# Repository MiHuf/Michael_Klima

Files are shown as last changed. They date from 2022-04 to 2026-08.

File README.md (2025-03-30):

[Zu bearbeiten mit keenwrite.bin oder retext,  File README.md, Version 2025-03-30]: #
# Michael_Klima

Michaels Raumklima-Monitor. Inspiriert durch den Artikel
"IKEA Vindiktning hacken", siehe Make 5/2021, Seite 14 ff und hier: <https://techtest.org/anleitung-wlan-feinstaub-und-temperatur-sensor-ikea-vindriktning-hack/>

Der Code ist vorbereitet für den Anschluß weiterer Sensoren.
Im Original: VINDRIKTNING Ikea Luftgüte Sensor -> AdafruitIO

Mai 2022: Absolute (aber ungenaue) Helligkeitsmessung mit einem LDR Photowiderstand. Parameter müssen in der jeweiligen Zugangsdaten-Datei xxx.h angepasst werden. Siehe LDR-Photometer.pdf.

Sept. 2023: Luftdruck-Sensor BME280 eingebaut, CO2-Sensor SCD-30 vorbereitet.

Okt. 2024: Doku ergänzt.

Nov. 2024: MQTT funktioniert, Doku aktualisiert

Dez. 2024: MQTT jetzt sowohl mit Port 1883 als auch mit Port 8883 (TLS)

Mrz. 2025: Erweitert auf beliebig viele (zur Zeit 10) DS18x20 Sensoren

## Konfiguration und Installation

  1. Den Projekt-Ordner "Michael_Klima" von github.com/MiHuf/ klonen.

  2. Der Mircocontroller "Wemos D1 Mini ESP8266" wird programmiert mit der Arduino IDE <https://www.heise.de/ct/artikel/Arduino-IDE-installieren-und-fit-machen-fuer-ESP8266-und-ESP32-4130814.html>. Die Sprache ist im Wesentlichen C++.  
Vorher müssen noch einige Dateien angepasst werden:

  3. ***Datei "Michael_Klima.h", Zeile 51:***

      #include "privat.h"   
Die Datei "privat.h" enthält persönliche Zugangsdaten. Am besten nimmt man die als Gerüst und kopiert sie in eine neue Datei, z.B. "_mein_privat.h". Alle Dateien mit einem Unterstrich am Anfang des Namens werden von git nicht im öffentlichen Repository gespeichert.  
Anschließend muss die Zeile 56 entsprechend angepasst werden:  
  #include "_mein_privat.h"  

  4. ***Datei "_mein_privat.h":*** 
  
      4.1. In den Zeilen 23 bis 52 sind die aktuell vorhandenden Sensoren definiert, die Zeilen können gelöscht oder umgeordnet werden. 
 
      4.2. In die Sektion "\***** My Settings" kommen dann die privaten Zugangsdaten:  
   #define WIFI_SSID "xxx"  
   #define WIFI_PASS "yyy"  
Das sind die Zugangsdaten zum lokalen WLAN des Routers und ggf. zum Internet.

     4.3. Falls erforderlich, Daten für den MQTT Broker konfigurieren: TOPIC, MQTT_BROKER, MQTT_PORT,  MQTT_USER, MQTT_PASS, ...  
     Achtung: Falls "MQTT_PORT 8883" für TLS gesetzt wird, muss zusätzlich eine Zeile  
   #define MQTT_TLS  
eingefügt werden. Für "MQTT_PORT 1883" muss diese Zeile auskommentert werden.  

      4.4 Der Wemos D1 Mini ESP8266 in dem Modul spannt eigenes WLAN auf, das wird konfiguriert in den Zeilen  
   #define APSSID "zzz"  
   #define OPEN_WIFI  
Das sind die Zugangsdaten zum internen WLAN des ESP8266 (ohne Passwort).

5. ***Anschließend mit der Arduino IDE kompiliern,*** das Modul mit einem Mirco-USB Kabel an den PC anschließen und den Binär-Code auf den D1 Mini hochladen.

    Der ESP8266 konfiguriert sich dann und startet das Programm. Das kann bis zu 2 Minuten dauern, am Ende wird die eingebaute LED fünf mal blinken.

6. ***Für den nächsten Schritt gibt es 2 Möglichkeiten:***

    6.1 Mit einem anderen PC / Touchpad / Handy das WLAN Netzwerk scannen und mit der in Abschnitt 4.2 definierten APSSID (z.B. "zzz") verbinden.

      Dann mit einem Browser (Firefox, Chrome) die Seite `http://192.168.4.1` öffnen. Dann sollte sich eine Seite mit wichtigen Informationen über das Netzwerk öffnen. Merke dir aus der Zeile "External WLAN SSID" den Wert von "IP address" und aus der folgenden Zeile den Wert von "Hostname on Router".

      Falls in der Zeile "External WLAN SSID" keine IP-Adresse angezeigt wird, hat die Verbindung zum WLAN des Routers nicht geklappt. Überprüfe die Zugangsdaten und wiederhole ab Abschnitt 4.2.

    6.2 Gehe auf die Administrations-Seite des Routers, lass dir im Abschnitt "WLAN > Funknetz" die verbundenen Geräte anzeigen. Der ESP8266 sollte unter dem Namen Raumklima-XXX sichtbar sein, wobei XXX die letzten 6 Hex-Ziffern der MAC Addresse ist. Merke dir die zughörige IP-Adresse.

7. ***Geschafft!***
  Ab jetzt sollte der Raumklima Monitor von überall im LAN mit einem Browser sichtbar sein, entweder über die obige IP-Adresse oder über die URL `"http://raumklima-xxx"`.

8. ***Optional:***
  Um einen Zugriff von außen übers Internet einzurichten, muss man im Router einen DDNS-Client installieren und konfigurieren und ferner für raumklima-xxx eine Port-Weiterleitung zur <IP-Adresse des Moduls>:80 erstellen.

## Life Demo

Klicke hier: <http://hufschmidt.ddns.krude.de:8086/> oder <http://hufschmidt.ddns.krude.de:8087/>

## Setup März 2022:

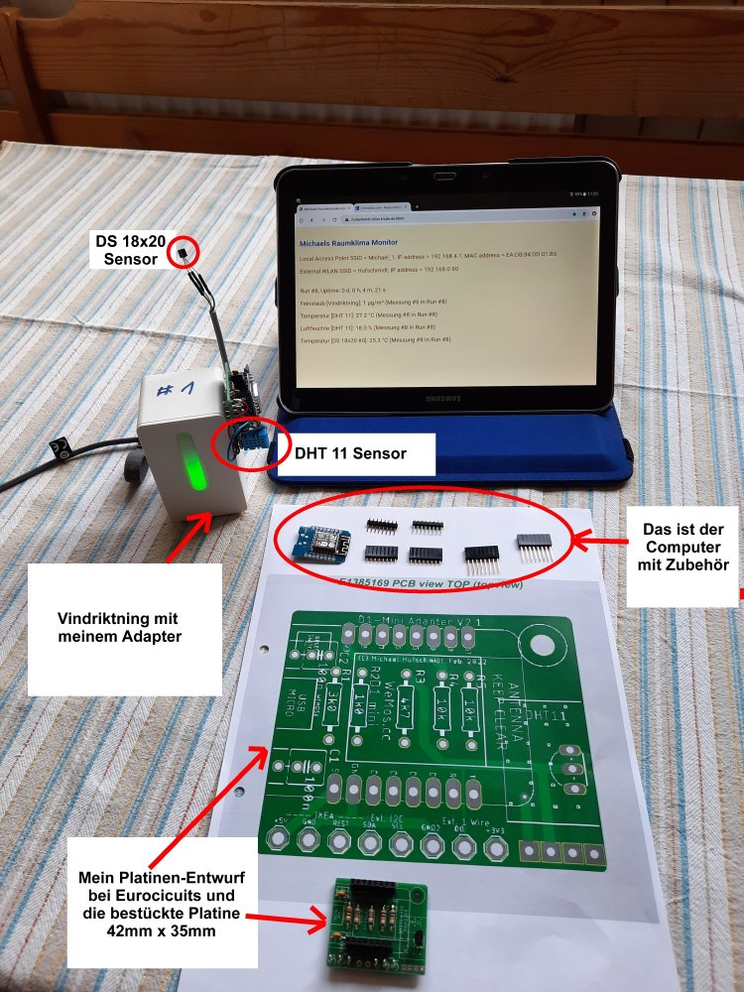
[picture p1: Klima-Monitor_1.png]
Foto Setup


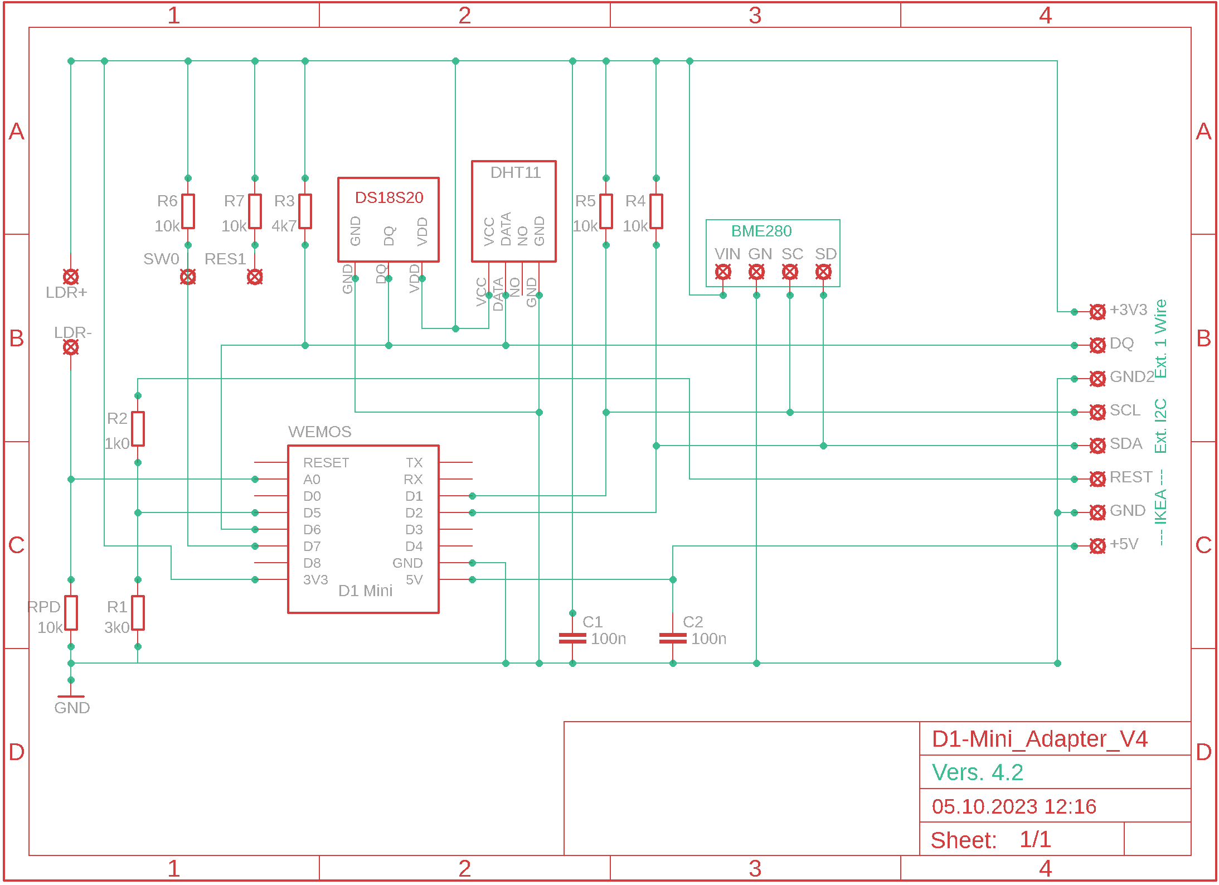
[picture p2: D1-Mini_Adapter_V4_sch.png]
pdf Adapter Schematic Schaltplan


Und hier die Adapter-Platine (35mm x 42mm):

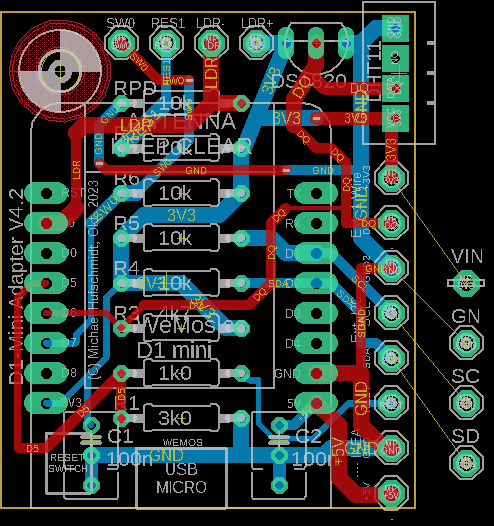
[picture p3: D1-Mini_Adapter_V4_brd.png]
pdf Adapter PCB Platine


## Quellen für den Arduino Code und für MQTT  Broker
|Was |URL|
|---|---|
|ESP8266:|<https://github.com/esp8266/Arduino/tree/master/libraries/ESP8266WiFi/>|
|Time-Server:|<https://werner.rothschopf.net/201802_arduino_esp8266_ntp.htm>|
|OneWire:|<https://github.com/PaulStoffregen/OneWire/blob/master/OneWire.h>|
| |<https://www.arduino.cc/reference/en/libraries/onewire/>|
|DS18B20:|<https://github.com/milesburton/Arduino-Temperature-Control-Library/blob/master/DallasTemperature.h>|
|DHT11:  |<https://cdn-learn.adafruit.com/downloads/pdf/dht.pdf>|
| |<https://github.com/adafruit/DHT-sensor-library>|
|BME280: |<https://www.az-delivery.de/products/gy-bme280>|
|SCD-30: |<https://www.adafruit.com/product/4867>|
| |<https://learn.adafruit.com/adafruit-scd30/arduino>|
|MQTT Client Lib|<https://github.com/knolleary/pubsubclient>|
|MQTT Broker Mosquitto:|<http://www.steves-internet-guide.com/install-mosquitto-linux/>|
|InfluxDB:|<https://www.ionos.de/digitalguide/hosting/hosting-technik/was-ist-influxdb/>|
|Grafana: |<https://grafana.com/>|
|MQTT Client Software zum Testen|<http://mqtt-explorer.com/>|
|MQTT Broker, Übersicht|<https://mntolia.com/10-free-public-private-mqtt-brokers-for-testing-prototyping/>|
|MQTT Broker HiveMQ:| <https://www.hivemq.com/>|
|MQTT Broker Cedalo / Pro Mosquitto| <https://test.mosquitto.org/>|
|MQTT Broker flespi|<https://flespi.com/>|
|MQTT Broker sensatio:|<https://www.sensatio.io/>|

---

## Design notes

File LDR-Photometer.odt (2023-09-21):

LDR-Photometer

Dies ist der Versuch, eine quantitative Helligkeitsanzeige mit einem LDR Photowiderstand zu realisieren. Hardware ist ein ESP8255 (https://www.wemos.cc/en/latest/d1/d1_mini.html) Microcontroller an dessen Analog-Eingang A0 neben einem Pull-Down Widerstand Rpd ein LDR vom Typ GL 55xx angeschlossen ist (Preis für 30 Stück: 1,89 € bei Eckstein (https://eckstein-shop.de/30pcs6ValuesLichtempfindlicheWiederstC3A4ndePhotoresistor550655165528553755395549)).

Hier das Datenblatt (https://www.kth.se/social/files/54ef17dbf27654753f437c56/GL5537.pdf); die wichtigsten Daten für die Typen:

Typ | Light Resistance R10 / kΩ | Dark Resistance R0 / MΩ
GL 5516 | 5 – 10 | 0.5 | 0.5
GL 5528 | 10 – 20 | 1 | 0.6
GL 5537-1 | 20 – 30 | 2 | 0.6
GL 5537-2 | 30 – 50 | 3 | 0.7
GL 5539 | 50 – 100 | 5 | 0.8
GL 5549 | 100 – 200 | 10 | 0.9

Die Sensitivität γ ist im Datenblatt definiert durch die Gleichung wobei R10 bzw. R100 die Widerstandswerte bei einer Beleuchtungsstärke von B = 10 lx bzw. 100 lx sind. Die Einheit der Beleuchtungsstärke ist das Lux (https://de.wikipedia.org/wiki/Beleuchtungsstärke), abgekürzt lx.

Für eine beliebige Beleuchtungsstärke B definiere ich nun RB als den Widerstandswert des mit der Beleuchtungsstärke B bestrahlten LDRs sowie . Für das interessierende Intervall von B = 1 lx (Kerze in 1 m Abstand) bis 10.000 lx (im Sommer im Schatten) werden nun folgenden Annahmen gemacht:

- Es gilt , d.h. es zeigt sich in der doppelt logarithmischen Darstellung ein über mehrere Dekaden linearer Verlauf zwischen Widerstandswert und Beleuchtungsstärke. Das wird nahegelegt durch die Graphen im Datenblatt.
- Die Temperaturabhängigkeit kann vernachlässigt werden.

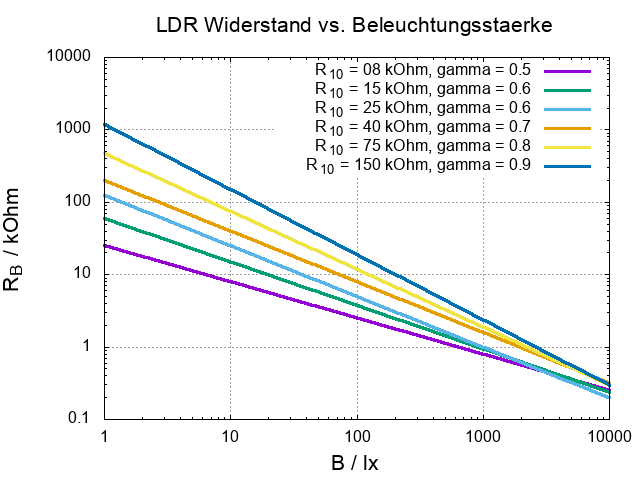
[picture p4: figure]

Damit kann nun RB aus R10 und γ wie folgt berechnet werden:

(1)

und umgekehrt:

(2) .

Der 10-Bit A/D Wandler im ESP8255 hat einen Eingangsspannungs-Bereich zwischen 0 V und 3,3 V. (Achtung! Das gilt nur für die Development Boards wie ESP8266 12-E NodeMCU Kit, WeMos D1 Mini, … Der nackte ESP8255 Chip hat einen Eingangsspannungs-Bereich von 0 V bis 1 V.) Der Eingang wird in der Arduino IDE angesprochen mit der Funktion ADC = analogRead(A0), die eine Integer Zahl zwischen 0 und 1024 zurückgibt.

Mit einem Spannungsteiler bestehend aus einem Pull-Down Widerstand Rpd zwischen A0 und GND und dem LDR zwischen A0 und +3,3 V (mit dieser Polung ergibt sich ein monoton wachsender Zusammenhang zwischen ADC-Wert und Beleuchtungsstärke B) ergibt sich dann:

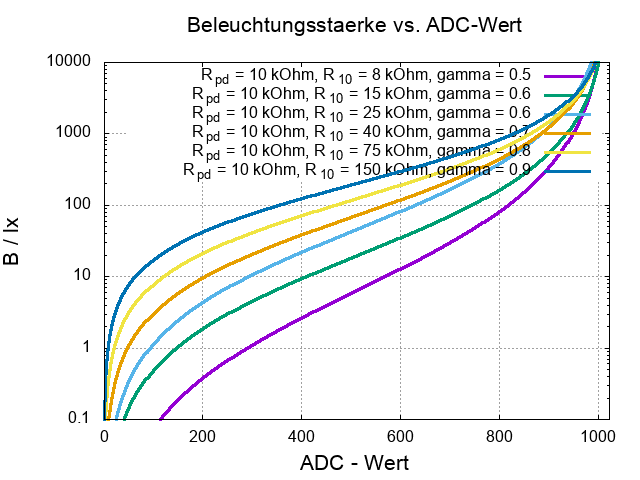
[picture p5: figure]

(3) .

Gleichung (3) eingesetzt in (2) liefert schließlich den mathematischen Zusammenhang zwischen ADC-Wert und Beleuchtungsstärke B:

(4) .

Wertetabelle

Angenommene Parameter für Typ GL 5539:

Rpd = | 10.000 | Ω
R10 = | 75.000 | Ω
gamma = | 0,8
ADC-Wert | RB / Ω | B / lx
2 | 5.110.000 | 0,05
5 | 2.038.000 | 0,16
10 | 1.014.000 | 0,39
20 | 502.000 | 0,93
50 | 194.800 | 3,03
100 | 92.400 | 7,70
200 | 41.200 | 21,14
500 | 10.480 | 117,05
800 | 2.800 | 609,37
1000 | 240 | 13.139,01

Michael Hufschmidt

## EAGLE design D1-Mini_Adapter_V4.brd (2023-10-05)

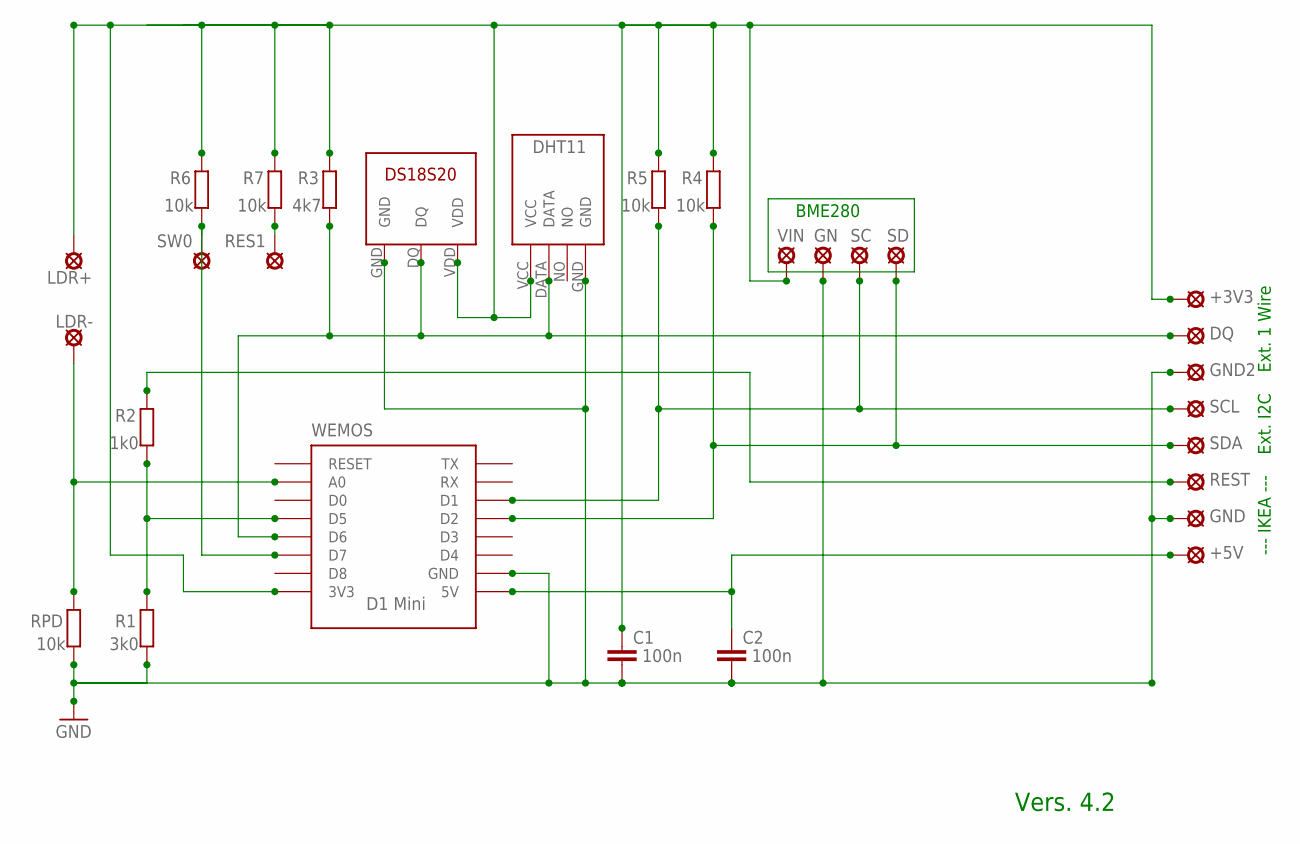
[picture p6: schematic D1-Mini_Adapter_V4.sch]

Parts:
+3V3, +5V: SE13
C1, C2: 100n; C025_050-045X075
DQ: SE13
DS1820: DS18S20; DS18S20-PACKAGE
GN: SE13
GND, GND2: SE13
LDR+: SE13
LDR-: SE13
R1: 3k0; 0207/10
R2: 1k0; 0207/10
R3: 4k7; 0207/10
R4, R5, R6, R7: 10k; 0207/10
RES1: SE13
REST: SE13
RPD: 10k; 0207/10
SC: SE13
SCL: SE13
SD: SE13
SDA: SE13
SW0: SE13
U$1: DHT11-PION.
VIN: LSP13
WEMOS: D1 Mini; WEMOS-D1-MINI

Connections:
3V3: +3V3.MP, C1.1, DS1820.VDD, LDR+.MP, R3.2, R4.2, R5.2, R6.2, R7.2, U$1.VCC, VIN.MP, WEMOS.3V3
+5V: +5V.MP, C2.1, WEMOS.5V
D5: R1.2, R2.1, WEMOS.D5
DQ: DQ.MP, DS1820.DQ, R3.1, U$1.DATA, WEMOS.D6
GND: C1.2, C2.2, DS1820.GND, GN.MP, GND.MP, GND2.MP, R1.1, RPD.1, U$1.GND, WEMOS.GND
LDR: LDR-.MP, RPD.2, WEMOS.A0
RES1: R7.1, RES1.MP
REST: R2.2, REST.MP
SCL: R5.1, SC.MP, SCL.MP, WEMOS.D1
SDA: R4.1, SD.MP, SDA.MP, WEMOS.D2
SW0: R6.1, SW0.MP, WEMOS.D7

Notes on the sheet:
--- IKEA ---
Ext. I2C
Ext. 1 Wire
Vers. 4.2
BME280

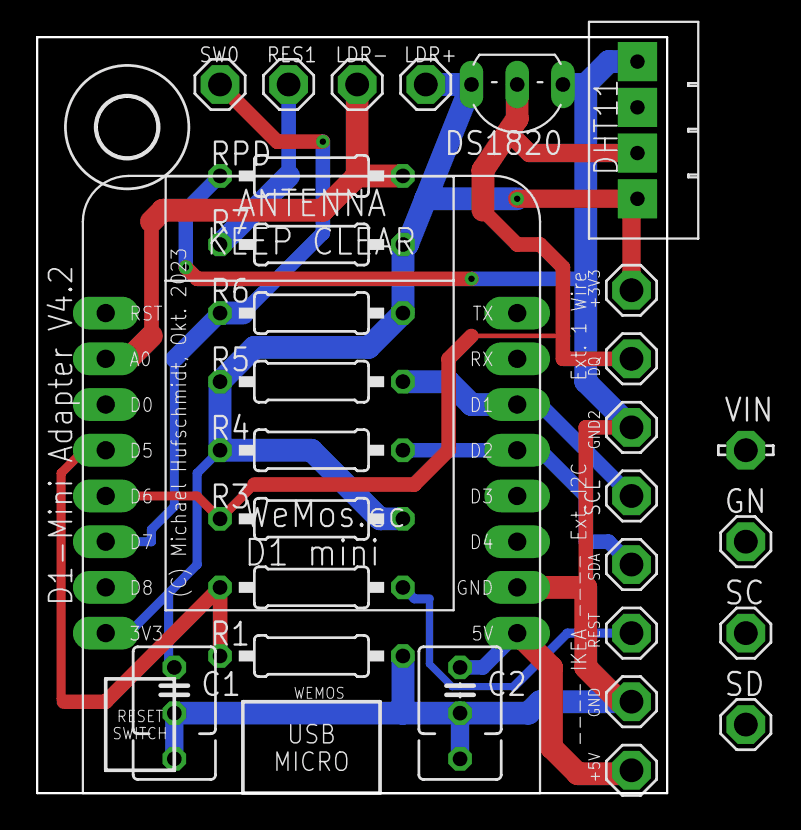
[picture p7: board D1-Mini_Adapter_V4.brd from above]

Board: 2 copper layers, 35.0 x 42.0 mm, 30 parts (0 on the bottom side), 11 nets.

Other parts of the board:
U$2: 3,3

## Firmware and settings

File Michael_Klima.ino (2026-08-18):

/*****************************************************************************
   File:              Michael_Klima.ino, Version 1.0
   Created:           2021-12-17
   Last modification: 2026-08-18
   Program size:      Global Vars: 36604 / 80192 bytes (45%),
    (using privat.h)  Instruction RAM: 63003 / 65536 bytes (96%)
                      Code in Flash: 416232 / 1048576 bytes (39%)
   Author and (C):    Michael Hufschmidt <michael@hufschmidt-web.de>
   Projekt Source:    https://github.com/MiHuf/Michael_Klima
   License:           https://creativecommons.org/licenses/by-nc-sa/3.0/de/
 * ***************************************************************************/
const String version = "2026-08-18";
const String ide = "arduino IDE 2.3.10";
/* Michaels Raumklima-Monitor. Inspiriert durch den Artikel "IKEA Vindiktning
   hacken", siehe Make 5/2021, Seite 14 ff und hier:
   https://techtest.org/anleitung-wlan-feinstaub-und-temperatur-sensor-ikea-vindriktning-hack/
   
   Im Original: VINDRIKTNING Ikea Luftguete Sensor -> AdafruitIO
   Siehe https://github.com/MiHuf/Michael_Klima#readme
   in the IDE: Include board
          https://arduino.esp8266.com/stable/package_esp8266com_index.json

  Additional board manager URLs: https://arduino.esp8266
  Boaard: LOLIN(WEMOS) D1 R2 & mini
 * ***************************************************************************/

// ***** Includes
#include <functional>
#include <ESP8266WiFi.h>
#include <ESP8266WebServer.h>
#include <time.h>
#include <TZ.h>
#include <SoftwareSerial.h>
// https://github.com/knolleary/pubsubclient
#include <PubSubClient.h>
#include <CertStoreBearSSL.h>      // needed for HiveMQ with TLS (Port 8883)
#include <DallasTemperature.h>
// ***** For BME280 and SCD-30
// https://www.az-delivery.de/products/gy-bme280 (BME280)
// #include <OneWire.h>
// #include <Wire.h>
#include <Adafruit_Sensor.h>
// #include <DHT-sensor-library>
#include <DHT.h>
#include <Adafruit_BME280.h>
// https://www.adafruit.com/product/4867  (SCD-30)
// https://learn.adafruit.com/adafruit-scd30/arduino
#include <Adafruit_SCD30.h>
// ***** External definitions, constants and variables
#include "Michael_Klima.h"

// ***** Pin definitions
#define D1_MINI
#ifdef D1_MINI  // true for D1 Mini, =D4
  #define AN LOW
  #define AUS HIGH
#else                    // not a D1 Mini
  #define LED_BUILTIN 1  // LED for Digistump
  #define AN HIGH
  #define AUS LOW
#endif
// Original-Version aus Make 05/21:
// Version fuer mein Adapter-Board:
constexpr static const uint8_t PIN_UART_RX = D5;   // =GPIO14, used by IKEA SoftwareSerial
constexpr static const uint8_t PIN_UART_TX = D7;   // =GPIO13, used by IKEA SoftwareSerial
constexpr static const uint8_t SW0 = D7;           // =GPIO13
constexpr static const uint8_t SW1 = D5;           // =GPIO14
// ***** Warning! Boot fails if D3 or D4 are pulled LOW !!!
constexpr static const uint8_t SW2 = D3;           // =GPIO0, *** Warning ***
constexpr static const uint8_t SW3 = D4;           // =GPIO2  *** Warning, LED_BUILTIN ***
constexpr static const uint8_t ONE_WIRE_BUS = D6;  // =GPIO12 am Wemos D1 Mini
// default I2C Pins already defined in Aruino.h:
// constexpr static const uint8_t SCL = D1;        // =GPIO5, default I2C Pins
// constexpr static const uint8_t SDA = D2;        // =GPIO4, default I2C Pins
constexpr static const uint8_t ADC0 = A0;          // = Analog input, Pin 17

// ***** Global Settings
#define MY_TZ "CET-1CEST,M3.5.0/02,M10.5.0/03"
const String wotag[] = { "So", "Mo", "Di", "Mi", "Do", "Fr", "Sa" };
const uint8_t BLINK_COUNT = 5;  // Default Anzahl Lichtblitze
const uint16_t PUNKT = 200;     // Punktlaenge (Norm = 100 ms bei 60 BpM)
const uint16_t ABSTAND = 500;   // Punkt-Strich Abstand (Norm = 100 ms)
const uint16_t ZEICHEN = 1500;  // Buchstaben-Abstand im Wort (Norm = 3x Punkt)
//* Set these to your desired credentials. */
const char* extSsid = WIFI_SSID;
const char* extPassword = WIFI_PASS;
const char* mySsid = APSSID;
const char* myPassword = APPSK;
const char* mqtt_broker = MQTT_BROKER;
#ifdef MQTT_USER
  const char* mqtt_user = MQTT_USER;
  const char* mqtt_password = MQTT_PASS;
#else
  const char* mqtt_user = "";
  const char* mqtt_password = "";
#endif
#ifndef MQTT_CLIENT
  // Create a random client ID
  String mqtt_client_id_s = "ESP8266Client-" + String(random(0xffff), HEX);
#else 
  String mqtt_client_id_s = MQTT_CLIENT;
#endif
const char* mqtt_client_id = mqtt_client_id_s.c_str();
const String topic = TOPIC;
const uint8_t msg_buffer_size = MSG_BUFFER_SIZE;


// ***** Global Variables
String localIP_s, macAddress_s, hostname_s, externalIP_s, mqttWeb_s = MQTT_WEB;
bool wlanOK = false;
bool mqttConnectOK = false;
String mqtt_broker_s = String(MQTT_BROKER) + ":" + String(MQTT_PORT);
int mqttState = -1;
bool timeOK = false;
bool mySCD_global = false;
uint8_t connect_tries = 0;
time_t now;  // this is the epoch
tm tm;       // time information in a structure
#ifdef MY_TITLE
  String title = MY_TITLE;
#else
  String title = "Michaels Raumklima Monitor";
#endif
int sensorCount = sizeof(sensor) / sizeof(sensor_type);
uint8_t deviceCount = 0;             // Anzahl der OneWire - Clients
uint8_t dallasCount = 0;             // Anzahl der DS18x10 - Sensoren
// DallasTemperature.h, line 63: typedef uint8_t DeviceAddress[8];
DeviceAddress ds_Addr[MAX_DS_COUNT]; // alle  DS 18x20 Sensoren
uint8_t global_n = 0;
uint8_t serialRxBuf[80];
uint8_t rxBufIdx = 0;
unsigned long runID = 0;
unsigned long previousMillis = 0;
char msg[msg_buffer_size];
String startTime = "";
double rpd = RPD;     // LDR Pull-Down Resistor
double r10 = R10;     // LDR R(10 Lux)
double sens = GAMMA;  // LDR Gamma-Value / Sensitivity
uint8_t switches[] = {SW0, SW1, SW2, SW3};

// ***** Objects
SoftwareSerial sensorSerial(PIN_UART_RX, PIN_UART_TX);
ESP8266WebServer webServer(80);
#ifdef MQTT_TLS
  BearSSL::WiFiClientSecure espClient;
// BearSSL::CertStore certStore;
#else
  WiFiClient espClient;
#endif
PubSubClient client(espClient);
OneWire oneWire(ONE_WIRE_BUS);
DHT dht(ONE_WIRE_BUS, DHTTYPE, 6);
DallasTemperature ds(&oneWire);
Adafruit_BME280 bme;   // I2C Communication
Adafruit_SCD30 scd30;  // I2C Communication


// ***** General Functions
void blink(const uint8_t count = BLINK_COUNT) {
  pinMode(LED_BUILTIN, OUTPUT);
  digitalWrite(LED_BUILTIN, AUS);
  delay(ZEICHEN);
  for (uint8_t i = 0; i < count; i++) {
    //    Serial.printf("\nBlink #%d", i);
    digitalWrite(LED_BUILTIN, AN);
    delay(ABSTAND);
    digitalWrite(LED_BUILTIN, AUS);
    delay(ABSTAND);
  }
  delay(ZEICHEN);
  pinMode(LED_BUILTIN, INPUT_PULLUP);
}  // blink()

String deviceAddressToString(DeviceAddress a) {
  char buffer[32];
  snprintf(buffer, 30, "%0x %0x %0x %0x  %0x %0x %0x %0x",
           a[7], a[6], a[5], a[4], a[3], a[2], a[1], a[0]);
  return String(buffer);
}  // deviceAddressToString(...)


String lz(int num) {
  // add leading zero
  if (num >= 10) {
    return String(num);
  } else {
    return "0" + String(num);
  }
}  // lz()

String getTime() {
  String out = "";
  if (timeOK) {
    time(&now);              // read the current time
    localtime_r(&now, &tm);  // update the structure tm with the current time
    out += wotag[tm.tm_wday] + ", den ";
    out += lz(tm.tm_mday) + "."
           + lz((tm.tm_mon + 1)) + "."
           + String((tm.tm_year + 1900));
    out += " ";
    out += lz(tm.tm_hour) + ":"
           + lz(tm.tm_min) + ":"
           + lz(tm.tm_sec);
  }  // if
  return out;
}  // getTime()

String runInfo() {
  unsigned long currentMillis, d, h, m, s;
  currentMillis = millis();
  String info = "";
  s = currentMillis / 1000;
  m = s / 60;
  h = m / 60;
  d = h / 24;
  info += "\nRun #";
  info += String(runID);
  if (timeOK) {
    info += " vom " + getTime();
  }
  info += ", Uptime: " + String(d) + " d, ";
  info += String(h % 24) + " h, ";
  info += String(m % 60) + " m, ";
  info += String(s % 60) + " s ";
  return info;
}  // runInfo()


// ***** Setup Sensors

void Setup_Ikea (){
  // Software Serial für IKEA Sensor
  Serial.printf("Software UART (Ikea) on Pin %d\n", PIN_UART_RX);
  sensorSerial.begin(9600);
} // end Setup_Ikea

void Setup_oneWire() {
  pinMode(ONE_WIRE_BUS, INPUT);
  oneWire.begin(ONE_WIRE_BUS);
  if (oneWire.reset()) {
    Serial.printf("oneWire Bus on Pin %d\n", ONE_WIRE_BUS);
  } else {
    Serial.printf("No devices found on Pin %d\n", ONE_WIRE_BUS);
  }
  oneWire.begin(ONE_WIRE_BUS);
} // end Setup_oneWire()

void Setup_ds() {
  bool retry = true;
  String type;
  dht.begin();
  ds.begin();
  Serial.print("Parasite power is: ");
  if (ds.isParasitePowerMode())
    Serial.println("ON (2 wire)");
  else Serial.println("OFF (3 wire)");
  //  ds.setResolution(9);        // global resulution, default 9 Bit
    for (int i = 0; i < MAX_DS_COUNT; i++) {  // scan DS18x20 sensors
      // delay(1000);
      if (ds.getAddress(ds_Addr[i], i)) {
      type = ds_Addr[i][0] == DS18B20MODEL ? "DS18B20" : "DS18S20 / DS1820";
      Serial.println("Found Device #" + String(i) + " " + type + ", ROM-Address = "
                    + deviceAddressToString(ds_Addr[i]));
      dallasCount += 1;
      // ds.setResolution(ds_Addr[i], 11);     // resolutuion for this sensor
    } // end for - scan DS18x20 sensors
  }  // 
  Serial.printf("Found %d DS18x00 Sensor(s) \n", dallasCount);
} // end Setup_ds();

void Setup_BME280() {
  // Try to initialize Communication to BME280
  bool retry = true;
  uint8_t connect_tries = 0;
  unsigned status;
  delay(200);
  while (retry) {
    connect_tries += 1;
    retry = connect_tries < MAX_TRIES;
    status = bme.begin();
    if (status) {
      retry = false;
      Serial.println("Communication to BME280 established after " + String(connect_tries) + " tries.");
      Serial.print("SensorID was: 0x"); Serial.println(bme.sensorID(),16);
    } else {
      Serial.println("Communication to BME280 failed #"+ String(connect_tries));
      Serial.print("SensorID was: 0x"); Serial.println(bme.sensorID(),16);
      delay(100);
    }
  }  // End while
  // End Communication to BME280
} // end Setup_BME280()

void Setup_SCD30() {
  // Try to initialize Communication to SCD30
  bool retry = true;
  uint8_t connect_tries = 0;
  while (retry) {
    connect_tries += 1;
    retry = connect_tries < MAX_TRIES;
    if (scd30.begin()) {
      retry = false;
      Serial.println("Communication to SCD30 established after " + String(connect_tries) + " tries.");
      if (!scd30.setMeasurementInterval(15)){
        Serial.println("Failed to set measurement interval");
        while(1){ delay(10);}
        }      
      Serial.print("Measurement Interval: "); 
      Serial.print(scd30.getMeasurementInterval()); 
      Serial.println(" seconds");
    } else {
      Serial.println("Communication to SCD30 failed #"+ String(connect_tries));
      delay(200);
    }
  }  // End while
  if (connect_tries >= MAX_TRIES) {
    Serial.println("Could not find a valid SCD30 sensor after " + String(connect_tries) + " tries.");
  }
  // End Communication to SCD30
} // end Setup_SCD30() 

void Setup_ext() {
  // Setting extension switches and LDR
  pinMode(SW0, OUTPUT);
  pinMode(SW1, OUTPUT);
  pinMode(SW2, OUTPUT);
  pinMode(SW3, OUTPUT);
  digitalWrite(SW0, HIGH);
  digitalWrite(SW1, HIGH);
  digitalWrite(SW2, HIGH);
  digitalWrite(SW3, HIGH);
  pinMode(SW0, INPUT_PULLUP);  // no external pullup needed
  pinMode(SW1, INPUT_PULLUP);  // no external pullup needed
  pinMode(SW2, INPUT_PULLUP);  // no external pullup needed
  pinMode(SW3, INPUT_PULLUP);  // no external pullup needed
  Serial.printf("Switch 0 on Pin %d\n", SW0);
  Serial.printf("Switch 1 on Pin %d\n", SW1);
  Serial.printf("Switch 2 on Pin %d\n", SW2);
  Serial.printf("Switch 3 on Pin %d\n", SW3);
  Serial.printf("ADC 0 on Pin %d\n", ADC0);
  Serial.printf("LDR-Params: Rpd = %f, R10 = %f, gamma = %f\n",
                rpd, r10, sens);
} // end Setup_ext()

void setupSensors() {
  Setup_Ikea();
  Setup_BME280();
  Setup_SCD30();
  Setup_oneWire();
  Setup_ds();
  Setup_ext();
}


// ***** Get Sensor Data Functions

String getDummy() {
  return "???";
}
String getRandom() {
  return String(random(20, 50));
}

String getIkeaData() {  // from the Make Magazin
  int data;
  uint8_t rxBufIdx = 0;
  uint8_t checksum = 0;
  // Sensor Serial aushorchen
  while ((sensorSerial.available() && rxBufIdx < 127) || rxBufIdx < 20) {
    serialRxBuf[rxBufIdx++] = sensorSerial.read();
    // Wenn es Probleme mit dem Empfang gibt:
    delay(15);
  }
  // Pruefsumme berechnen
  for (uint8_t i = 0; i < 20; i++) {
    checksum += serialRxBuf[i];
  }
  // Header und Pruefsumme checken
  if (serialRxBuf[0] == 0x16 && serialRxBuf[1] == 0x11 && serialRxBuf[2] == 0x0B && checksum == 0) {
    data = (serialRxBuf[5] << 8 | serialRxBuf[6]);
  } else {
    data = -1;
  }
  return String(data);
}  // getIkeaData()

String getDHTTemperature() {
  return String(dht.readTemperature(), 1);
}
String getDHTHumidity() {
  return String(dht.readHumidity(), 1);
}

String getDS1820() {
  if (dallasCount > global_n) {
    return readDS1820Temperature(ds_Addr[global_n]);
  } else {
    return "disconnected";
  }
}
String readDS1820Temperature(DeviceAddress addr) {
  bool addrOK;
  bool ok = false;
  String out = "";
  float temperature = 0.0;
  addrOK = addr[0] != 0;
  if (addrOK) {
    //  ds.setWaitForConversion(false);  // makes it async
    ds.requestTemperatures();
    //  ds.setWaitForConversion(true);
    if (!ds.isConversionComplete()) {
      delay(1000);
    }
    // Serial.println("New conversion for Device "
    //              + deviceAddressToString(addr));
    ok = ds.requestTemperaturesByAddress(addr);
  } else {
    return "disconnected";
  }  // if (addrOK)
  if (ok) {
    temperature = ds.getTempC(addr);
  } else {
    Serial.println("Error: requestTemperaturesByAddress");
    return "disconnected\n";
  }                                            // if(ok)
  if (temperature != DEVICE_DISCONNECTED_C) {  // DallasTemperature.h line 36
    return String(temperature, 1);
  } else {
    return "disconnected";
  }
}  // readDS1820Temperature

String myBME280Temperature() {
  return String(bme.readTemperature(), 1);
}  // myBME280Temperature
String myBME280Humidity() {
  return String(bme.readHumidity(), 0);
}  // myBME280Humidity
String myBME280Pressure() {
  return String(bme.readPressure() / 100.0F, 1);
}  // getBME280Pressure

bool mySCD_DataOK() {
  bool retry = true;
  bool ready, dataOK;
  uint8_t tries = 0;
  delay(200);
  while (retry) {
    tries += 1;
    retry = tries < 5;
    ready = scd30.dataReady();
    delay(50);
    dataOK = scd30.read();
    if (dataOK) {
      retry = false;
    } else {
      Serial.println("Error reading sensor data");
    } // if (dataOK)
  }  // while (retry)
   delay(200);
  return dataOK;
} // mySCD_DataOK()
String mySCD30Temperature() {
  String value = "no data";
  if (mySCD_global) {
    value = String(scd30.temperature, 1);
  }
  return value;
}  // mySCD30Temperature
String mySCD30Humidity() {
  String value = "no data";
  if (mySCD_global) {
    value = String(scd30.relative_humidity, 0);
  }
  return value;
}  // mySCD30Humidity
String mySCD30CO2() {
  String value = "no data";
  if (mySCD_global) {
    value = String(scd30.CO2, 3);
  }
  return value;
}  // mySCD30CO2

String getSwitch() {
  return readSwitch(switches[global_n]);
}
String readSwitch(uint8_t pin) {
  String out;
  if (digitalRead(pin)) {
    out = "open (High)";
  } else {
    out = "closed (Low = GND)";
  }
  return out;
}  // readSwitch
String getSwitchNum() {
  return readSwitchNum(switches[global_n]);
}
String readSwitchNum(uint8_t pin) {
  String out;
  if (digitalRead(pin)) {
    out = "1";
  } else {
    out = "0";
  }
  return out;
}  // readSwitch

String getADC0() {
  return String(analogRead(ADC0));
}  // getADC0()
String getLDR() {
  int adc = analogRead(ADC0);
  double b = 0.0;
  String out = "", bs = "";
  if (adc > 1 && adc <= 1023) {
    b = 10.0 * exp(-log((rpd / r10) * (1024.0 / adc - 1.0)) / sens);
    bs = b < 100.0 ? String(b, 2) : String(b, 0);
  } else {
    bs = "overflow";
  }
  out = "ADC = " + String(adc) + " => " + bs;  // », →, ≡ oder ⇔
  return out;
}  // getLDR()
String getLDRNumLog() {
  int adc = analogRead(ADC0);
  double b = 0.0;
  String bs = "";
  if (adc > 1 && adc <= 1023) {
    b = 10.0 * exp(-log((rpd / r10) * (1024.0 / adc - 1.0)) / sens);
    bs = String(log10(b), 3);
  } else {
    bs = "overflow";
  }
  return bs;
}  // getLDR()

void getSensorData() {
  String value = "";
  runID += 1;
  mySCD_global = mySCD_DataOK();
  for (uint8_t i = 0; i < sensorCount; i++) {
    global_n = sensor[i].n;    // Parameter for sensor_read
    if (sensor[i].active) {
      // delay(200);           // Bringt nix
      value = sensor[i].sensor_read();
      sensor[i].value = value;
      if (value != "disconnected" && value != "nan" && value != "???" && value != "inf") {
        sensor[i].measurement += 1;
        sensor[i].runID = runID;
      }  // if value
    }  // if active
  }    // for
}  // getSensorData()

String formatSensorData(bool html = false) {
  String out = "";
  out += html ? "<p>" : "\n";
  out += String(APSSID) + " gestartet" + startTime;
  out += html ? "</p>\r\n<p>" : "";
  out += runInfo();
  out += html ? "</p>\r\n" : "\n";
  for (uint8_t i = 0; i < sensorCount; i++) {
    if (sensor[i].active) {
      out += html ? "<p>" : "";
      out += sensor[i].param + ": " + sensor[i].value + " " + sensor[i].unit;
      out += " (Messung #" + String(sensor[i].measurement);
      out += " in Run #" + String(sensor[i].runID) + ")";
      out += html ? "</p> \r\n" : "\n";
    }  // if active
  }    // for i
  return out;
}  // formatSensorData()


// ***** Output Functions

void printSensorData() {
  Serial.print(formatSensorData());
}  // printSensorData()

void handleRoot() {
  /* Just a little test message.  Go to http://192.168.4.1 in a
     web browser connected to this access point to see it. */
  webServer.send(200, "text/html", "<h1>You are connected</h1>");
}  // handleRoot()

void handle_OnConnect() {
  // getSensorData();
  webServer.send(200, "text/html", buildHtml());
}  // handle_OnConnect()

void handle_NotFound() {
  webServer.send(404, "text/plain", "Not found");
}  // handle_NotFound()

String buildHtml() {
  String page = "<!DOCTYPE html> \r\n";
  page += "<html lang=\"de\">\r\n";
  page += "<head>\r\n";
  page += "<title>" + title + "</title>\r\n";
  // page += "<meta name=\"viewport\"";
  // page += " content=\"width=device-width, initial-scale=1.0,";
  // page += " user-scalable=no\">\r\n";
  page += "<meta http-equiv=\"content-type\" content=\"text/html; charset=utf-8\"> \r\n";
  page += "<meta name=\"language\" content=\"de\"> \r\n";
  page += "<meta http-equiv=\"refresh\" content=\"";
  page += String(refreshInterval) + "\">\r\n";
  page += "<style>\r\n";
  page += "  html {font-family: Helvetica; display: inline-block; ";
  page += "margin: 0px auto; text-align: left;}\r\n";
  page += "  body {background-color: #FFC; margin-top: 50px; margin-left: 20px;}\r\n";
  page += "  h1 {color: #33C; margin: 20px auto 30px;}\r\n";
  page += "  p {font-size: 24px; color: #933; margin-bottom: 10px;}\r\n";
  page += "</style>\r\n";
  page += "</head>\r\n";
  page += "<body>\r\n";
  page += "<div id=\"webpage\">\r\n";
  page += "<h1>" + title + "</h1> \r\n";
  page += "<h2> Version: " + version + ", IDE = " + ide + "</h2> \r\n";
  page += "<p>Siehe <a href=\"https://github.com/MiHuf/Michael_Klima\" target=\"_blank\">github.com/MiHuf/Michael_Klima</a></p>\r\n";
  page += "<p>Internal WLAN SSID = " + String(mySsid) + ", IP address = " + localIP_s + ", MAC address = " + macAddress_s + "</p> \r\n";
  page += "<p>Router's WLAN SSID = " + String(extSsid);
  if (wlanOK) {
    page += ", IP address = " + externalIP_s + "<br> \r\n";
    page += "Hostname on Router = " + hostname_s  + "<p> \r\n"; 
  } else {
    page += ", Timeout after " + String(wlanTimeout) + " s</p> \r\n";
  }
  #ifdef MQTT_BROKER
    page += "<p>MQTT Broker:Port = <a href=\"http://" + mqtt_broker_s + "\"  target=\"_blank\">" + mqtt_broker_s + "</a><br>\r\nMQTT User = " + String(mqtt_user) + "<br>MQTT Client id = " + mqtt_client_id_s + "<br>\r\n";
    page += "MQTT Topic = " +  topic + "/#<br>\r\n";
    page += "MQTT Monitor = <a href=\"" + mqttWeb_s + "\" target=\"_blank\">" + mqttWeb_s + "</a><br>\r\n";
    // page += " or <a href=\"https://console.hivemq.cloud/clusters/free/" + String(mqtt_broker) + "/web-client\" target=\"_blank\">HiveMQ Web-Client</a><br>\r\n";
    page += "MQTT Connection State = " + String(mqttState) + "</p>\r\n";
    if (!mqttConnectOK) {
      page += "<p> MQTT Timeout after " + String(mqttTimeout) + " s</p> \r\n";
    }
  #endif
  page += formatSensorData(true);
  page += "</div>\r\n";
  page += "</body>\r\n";
  page += "</html>\r\n";
  return page;
}  //  buildHtml()


// ***** MQTT Functions
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
void loop() {  // main code, repeatedly
  unsigned long currentMillis = millis();
  randomSeed(micros());
  webServer.handleClient();
  if (currentMillis - previousMillis >= 1000 * processInterval) {
    if (startTime == "" && timeOK) startTime = ": " + getTime();
    previousMillis = currentMillis;
    getSensorData();
    printSensorData();
    publishSensorData();
    #ifdef DO_BLINK
      blink(3);
    #endif
  }  // if (currentMillis ...
}  // loop()

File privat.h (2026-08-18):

/*****************************************************************************
   @file:             privat.h
   Created:           2022-04-05
   Last modification: 2025-08-18
   This is part of Michael_Klima.ino
   Author and (C):    Michael Hufschmidt <michael@hufschmidt-web.de>
   License:           https://creativecommons.org/licenses/by-nc-sa/3.0/de/
 * ***************************************************************************/
#ifndef PRIVAT_H
  #define PRIVAT_H
/******************** This is a template file, you need to adapt it **********/

/******************** Boot-Log with the Serial Monitor ***********************
 *  Copy the boot messages from the Serial Monitor and paste it here!
 *  Serial Monitor, Hardware:
 *  -------------------------
 *  
 *  
 * ***************************************************************************/
  // ***** My Sensor definition
#define DHTTYPE DHT11       // define the type of sensor (DHT11 or DHT22)
sensor_type sensor[] = {
  {"Random-Test [Zahl]", "0", "(20 ... 50)", 0, 0, "test/Zahl", true, getRandom, 0},
  { "Feinstaub [Vindriktning]", "0", "µg/m³", 0, 0,
    "Wohnzimmer/Feinstaub", true, getIkeaData, 0},
  { "Luftfeuchte [DHT11]", "0.0", "%", 0, 0,
    "Wohnzimmer/Luftfeuchte", false, getDHTHumidity, 0},
  { "Temperatur [DHT11]", "0.0", "°C", 0, 0,
    "Wohnzimmer/Temperatur_DHT", false, getDHTTemperature, 0},
  { "Temperatur [DS18x20 DS#0]", "0.0", "°C", 0, 0,
    "Wohnzimmer/Temperatur_0", true,  getDS1820, 0},
  { "Temperatur [DS18x20 DS#1]", "0.0", "°C", 0, 0,
    "Wohnzimmer/Temperatur_1", false, getDS1820, 1},
  { "Temperatur [DS18x20 DS#2]", "0.0", "°C", 0, 0,
    "Wohnzimmer/Temperatur_2", false, getDS1820, 2},
  { "Temperatur [DS18x20 DS#3]", "0.0", "°C", 0, 0,
    "Wohnzimmer/Temperatur_3", false, getDS1820, 3},
  { "Temperatur [DS18x20 DS#4]", "0.0", "°C", 0, 0,
    "Wohnzimmer/Temperatur_4", false, getDS1820, 4},
  { "Temperatur [DS18x20 DS#5]", "0.0", "°C", 0, 0,
    "Wohnzimmer/Temperatur_5", false, getDS1820, 5},
  { "Temperatur [DS18x20 DS#6]", "0.0", "°C", 0, 0,
    "Wohnzimmer/Temperatur_6", false, getDS1820, 6},
  { "Temperatur [DS18x20 DS#7]", "0.0", "°C", 0, 0,
    "Wohnzimmer/Temperatur_7", false, getDS1820, 7},
  { "Temperatur [DS18x20 DS#8]", "0.0", "°C", 0, 0,
    "Wohnzimmer/Temperatur_8", false, getDS1820, 8},
  { "Temperatur [DS18x20 DS#9]", "0.0", "°C", 0, 0,
    "Wohnzimmer/Temperatur_9", false, getDS1820, 9},
  { "Temperatur [BME280]", "0.0", "°C", 0, 0,
    "Wohnzimmer/Temperatur", false, myBME280Temperature, 0},
  { "Luftfeuchte [BME280]", "0.0", "%", 0, 0,
    "Wohnzimmer/Luftfeuchte", false, myBME280Humidity, 0},
  { "Luftdruck [BME280]", "0.0", "hPa", 0, 0,
    "Wohnzimmer/Luftdruck", false, myBME280Pressure, 0},
  { "Temperatur [SCD30]", "0.0", "°C", 0, 0,
    "Wohnzimmer/Temperatur", false, mySCD30Temperature, 0},
  { "Luftfeuchte [SCD30]", "0.0", "%", 0, 0,
    "Wohnzimmer/Luftfeuchte", false, mySCD30Humidity, 0},
  { "CO₂ - Gehalt [SCD30]", "0.0", "ppm", 0, 0,
    "Wohnzimmer/CO2", false, mySCD30CO2 },
  { "Helligkeit [LDR GL5539]", "0", "Lux", 0, 0, "", true, getLDR, 0},
  { "Log10 Helligkeit in Lux [LDR GL5539]", "0", "", 0, 0,
     "Log10Helligkeit", false, getLDRNumLog, 0},
  { "Schalter SW0", "open (High)", "", 0, 0, "", true,  getSwitch, 0},
  { "Schalter SW1", "open (High)", "", 0, 0, "", false, getSwitch, 1},
  { "Schalter SW2", "open (High)", "", 0, 0, "", false, getSwitch, 2},
  { "Schalter SW3", "open (High)", "", 0, 0, "", false, getSwitch, 3}
};  
  // ***** My Settings
  // #define MY_TITLE "Raumklima Monitor"  // uncomment for own title
  #define WIFI_SSID "xxx"
  #define WIFI_PASS "yyy"
  // Local Access Point Parameters, Michael Hufschmidt, 2022-01-12
  #define APSSID "zzz"
  // Servername for the DHCP-Server in the Router. Make sure that it is
  // uniqe within the LAN. Comment out to automatically set a name
  // based on the last hex digits of the macAddress.
  // #define MY_SERVERNAME "Raumklima-zzz"  
  #define OPEN_WIFI            // comment out for protected WiFi with APSSK
  #define APPSK  "geheim123"   // Min. 8 characters

  // MQTT Stuff
  #define TOPIC "MyTest"
  #define MQTT_CLIENT "Raumklima_xxx"
  #define IS_HIVEMQ
  // Assume using HIVEMQ
    #ifdef IS_HIVEMQ
    #define MQTT_BROKER "broker.hivemq.com"
    #define MQTT_PORT 8883
    #define MQTT_TLS
    #define MQTT_WEB "https://console.hivemq.cloud/"
    #define MQTT_USER "aaa"
    #define MQTT_PASS "bbb"
  #endif  // IS_HIVEMQ

  #define HAS_INTERNET        // comment out if not
  #define MY_NTP_SERVER "at.pool.ntp.org"

  // LDR Parameters for Type = GL 5539:
  #define RPD 10.0e3      // LDR Pull-Down Resistor
  #define R10 75.0e3      // LDR R(10 Lux)
  #define GAMMA 0.8       // LDR Gamma-Value / Sensitivity

  #define  INDIVIDUAL_TIMING
  #ifdef INDIVIDUAL_TIMING
  // #define DO_BLINK                         // Blink at the end of loop()
    const unsigned long wlanTimeout = 60;     // timeout in seconds
    const unsigned long mqttTimeout = 60;     // timeout in seconds
    const unsigned long processInterval = 60; // process interval in seconds
    const unsigned long refreshInterval = 60; // HTML refresh in seconds
  #endif                  // INDIVIDUAL_TIMING

#endif // PRIVAT_H

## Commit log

2022-04-29 separate file for sensor definition
2022-05-05 MY_NTP_SERVER verschoben von Michael_Klima.ino in die User-Files
2022-05-07 Vorbereitet für einen Analog-Sensor
2022-05-07 Michael_Sensoren.h deleted, Sensor-Definitions moved to Michael_Klima.h and the individual user files
2022-05-10 fixed unclear line comment for OPEN_WIFI
    [privat.h]
2022-05-31 Bugfix in den Plots auf Seite 2, Wertetabelle hinzugefügt
    [LDR-Photometrie_Wertetabelle.ods]
2022-06-14 now accepting arbitrary order of the sensor array
2022-06-20 compiler flags modified, typo corrected
    [Michael_Klima.ino, privat.h]
2022-06-22 fixed logical bug in getLDR()
    [Michael_Klima.ino]
2022-12-13 PCB Version 3.1
2022-12-15 Silkscreen improved
2022-12-15 Schematics aktualisiert
2022-12-15 Filename schematic fixed
2023-07-09 Eagle files added
    [D1-Mini_Adapter.brd, D1-Mini_Adapter.sch]
2023-07-11 Schaltplan übersichtlicher
    [D1-Mini_Adapter.brd, D1-Mini_Adapter.sch]
2023-09-11 Added Sensores BME280 and SCD-30
2023-09-12 preparing more sensors, documentation
2023-09-14 minor improvements in sensor detection
2023-09-21 calculation for Rpd = 10 kOhm
    [LDR-Photometrie_Wertetabelle.ods]
2023-09-28 Fixed bad HTML Code in buildHtml()
    [Michael_Klima.ino]
2023-09-29 New PCS Version 4.1
    [D1-Mini_Adapter_V4.brd, D1-Mini_Adapter_V4.sch]
2023-09-29 Board V4.1
2023-09-29 Documentation adapted for PCB Version 4.1
2023-10-05 PCB and schema Version 4.2
    [D1-Mini_Adapter_V4.brd, D1-Mini_Adapter_V4.sch]
2024-10-06 Abschnitt Konfiguration und Installation ausführlicher
2024-11-04 MQTT publish now with timestamp before sensor data
2024-12-08 Switch between Ports 1883 and 8883 now with compiler directive MQTT_TLS
2025-03-29 Erweitert auf beliebig viele (zur Zeit 5) DS18x20 Sensoren
2025-03-30 Kosmetik & max. Anzahl DS-Sensoren jetzt 10
